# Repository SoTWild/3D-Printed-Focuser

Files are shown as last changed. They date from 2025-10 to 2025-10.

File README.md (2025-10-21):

# 3D打印颗粒对焦器

###### 【Designed By Dioxgen】

## 概述

这是一款基于 **SOLIDWORKS** 设计的 3D 打印**暗房颗粒对焦（放大）器**。

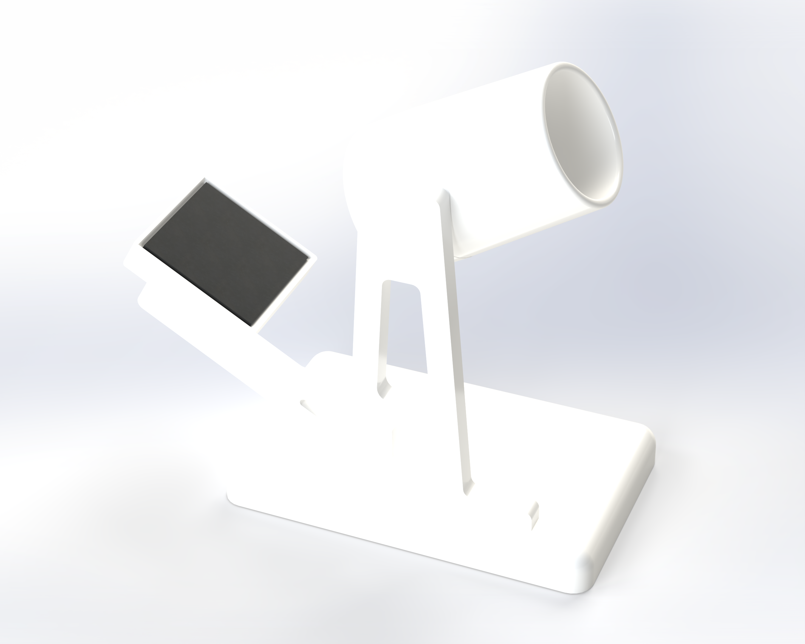
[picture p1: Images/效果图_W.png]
效果图_W


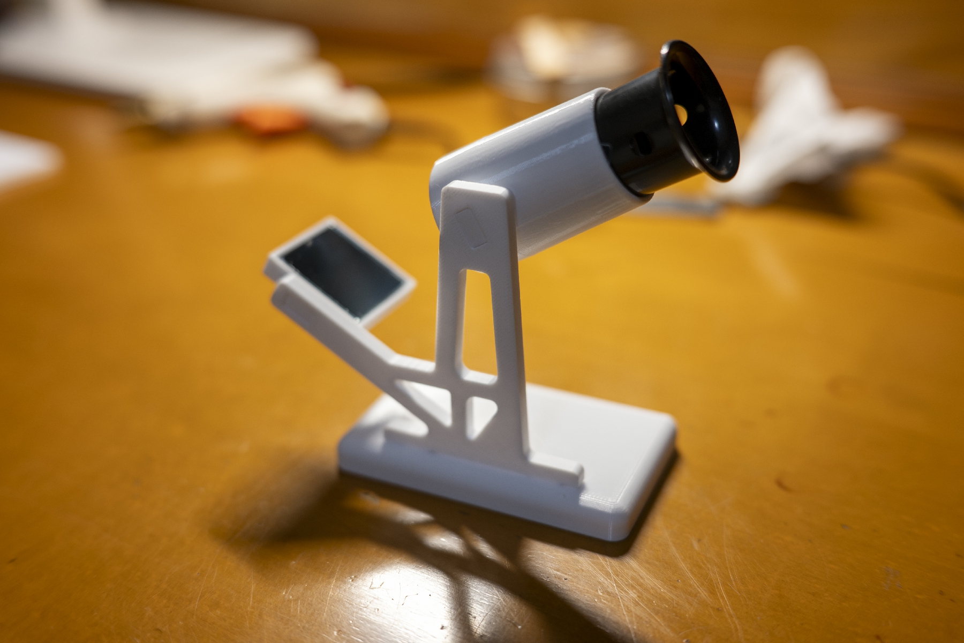
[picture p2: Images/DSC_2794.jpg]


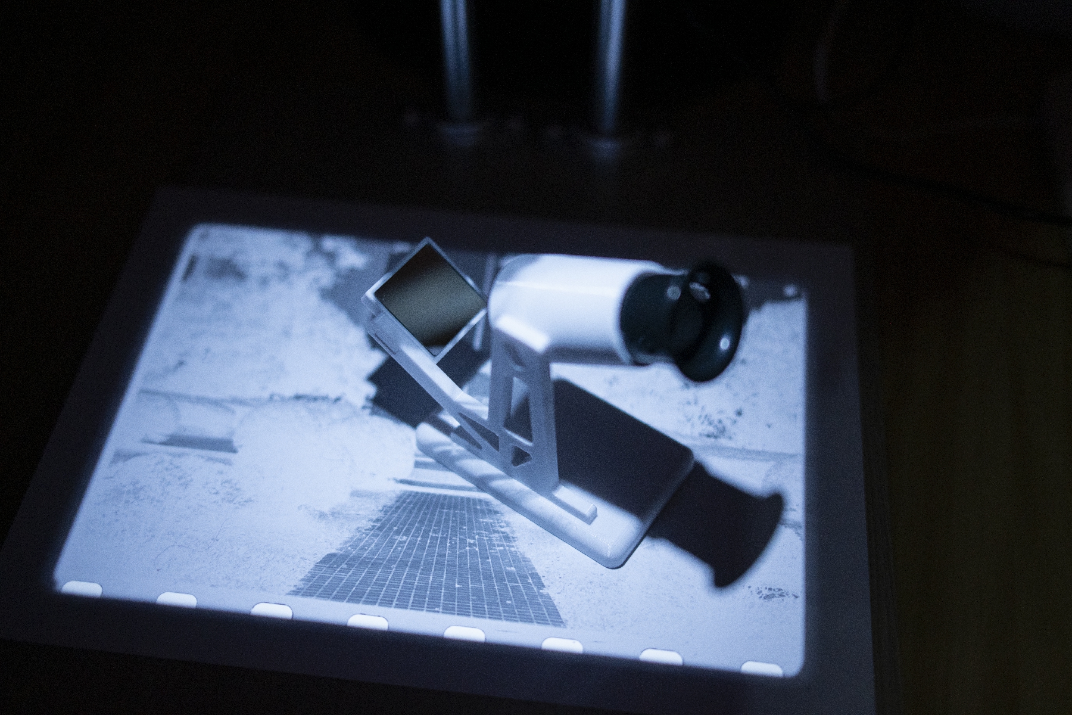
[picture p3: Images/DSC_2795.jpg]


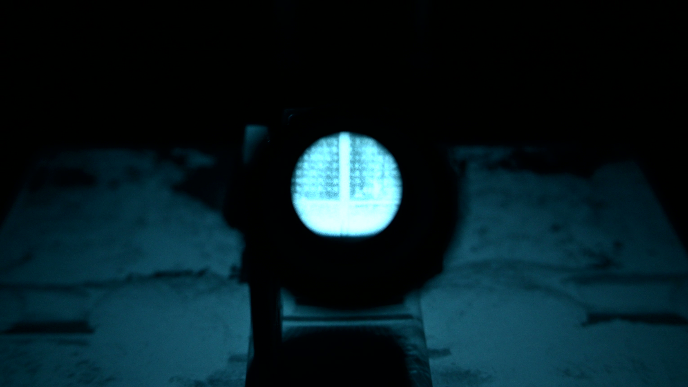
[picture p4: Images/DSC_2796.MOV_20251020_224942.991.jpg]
DSC_2796.MOV_20251020_224942.991


## 制作

### 准备：

#### 主体：

将 `STL` 文件夹中的 4 个组件全部 3D 打印。

以下是示例工艺：

> 黑色 PETG
>
> `15%` 填充

#### 目镜：

关键词：眼夹式目镜放大镜

规格：`5~10X` 放大

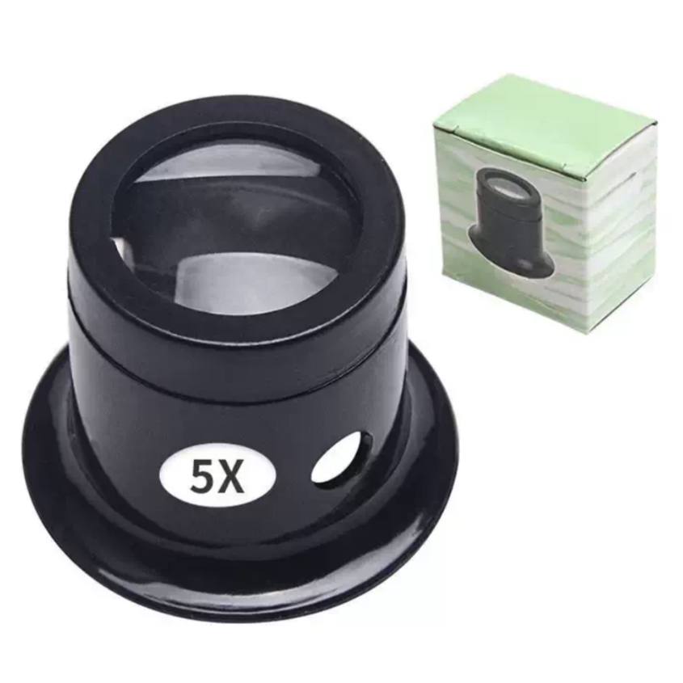
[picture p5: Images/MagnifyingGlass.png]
MagnifyingGlass


#### 镜片：

`3x3cm`，厚 `1mm` 平面镜。

#### 磨砂屏：

定制 `Φ=30mm`，厚 `2mm` 圆形亚克力**单面**磨砂片。

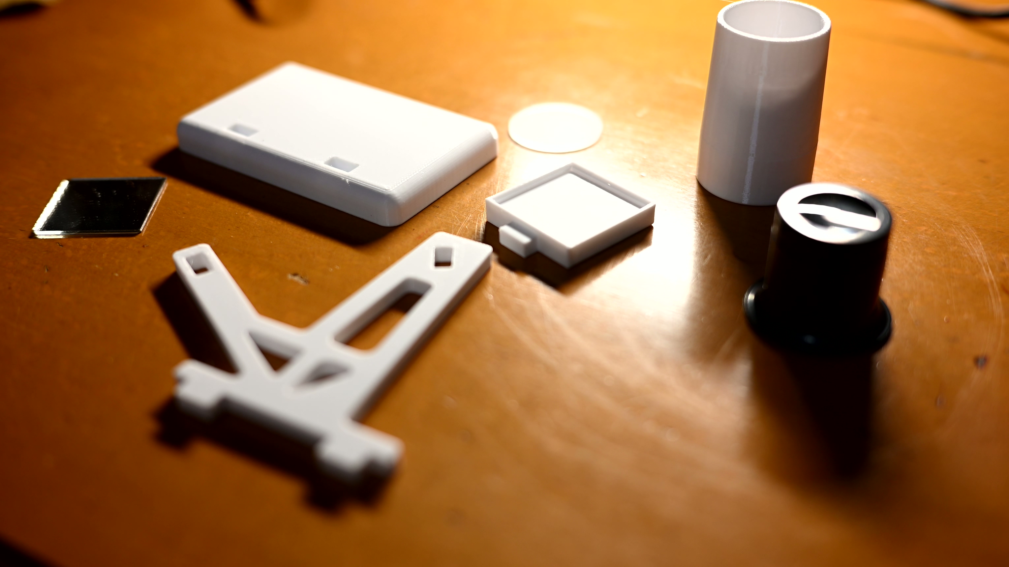
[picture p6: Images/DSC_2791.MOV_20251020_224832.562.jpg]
DSC_2791.MOV_20251020_224832.562


### 组装：

1）将 `磨砂屏` 通过少量胶水固定在 `目镜座` 较**大**开口的部位。

> 注：磨砂面朝**外**。

2）将 `目镜` 卡入、胶水固定至 `目镜座` 另一头。

3）将 `镜片` 通过少量胶水固定在 `镜片平台` 内。

4）将 `镜片平台` 和 `磨砂屏-目镜座` 嵌入 `支架` 中，随后，将这个装配体**嵌入** `底座`。

> 注：没有设置适当旷量，请稍作打磨后安装。

以上组装不计顺序。

### 原理：

利用**平面镜反射**原理，将放大镜头产生的实像反射至磨砂片处，同时保持总体光路**长度不变**。

> 这个例子中光路长度为 `49.01mm`。

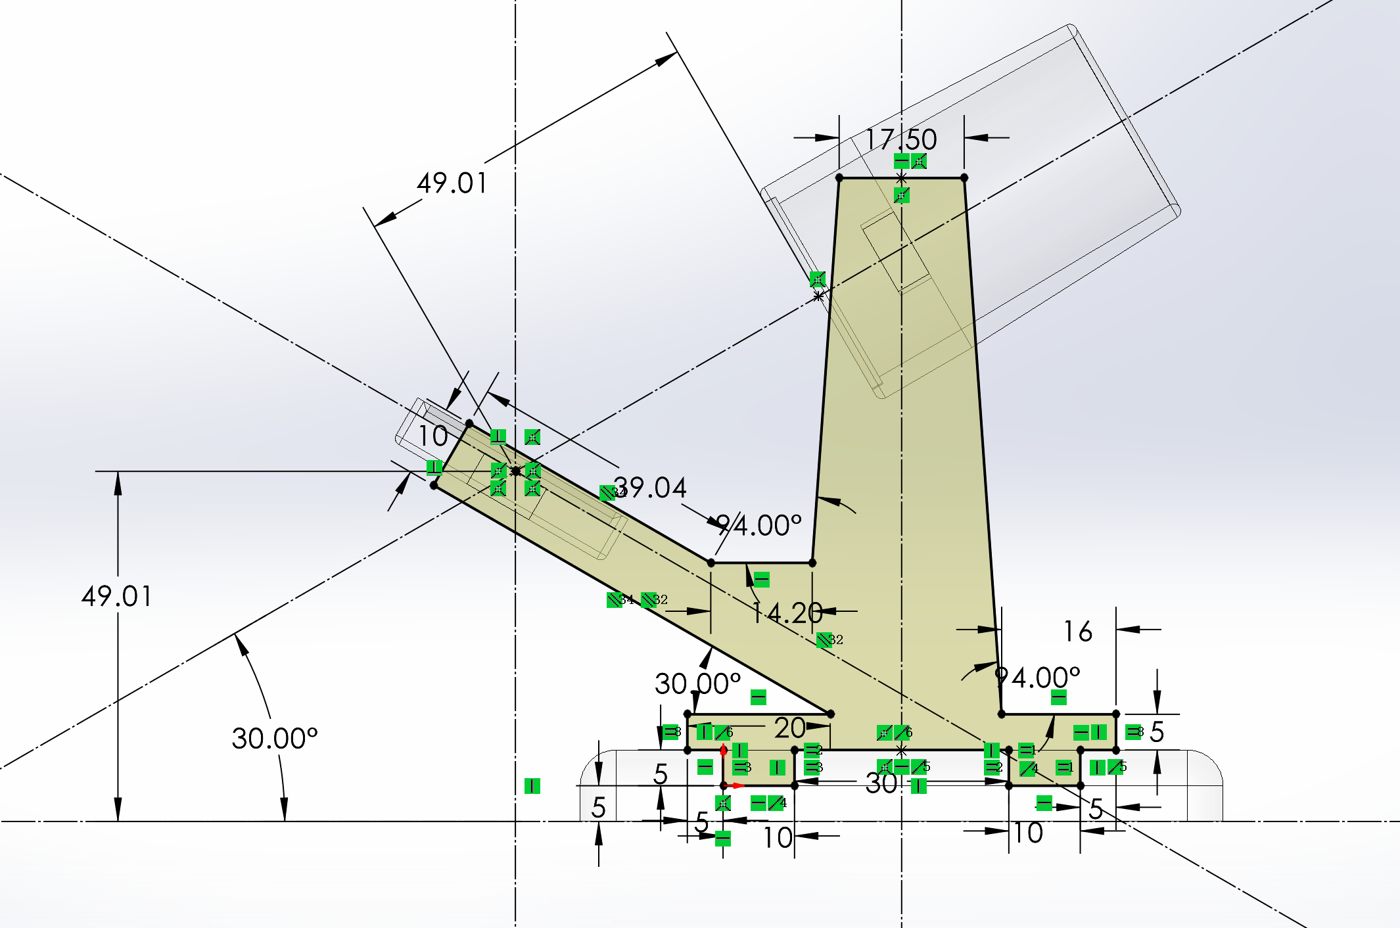
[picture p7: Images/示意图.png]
示意图


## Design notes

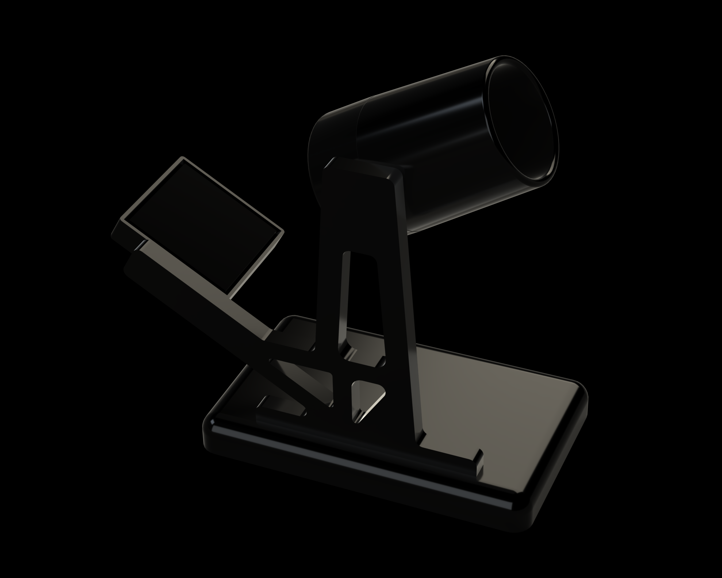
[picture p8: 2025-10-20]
Images/效果图_B.png

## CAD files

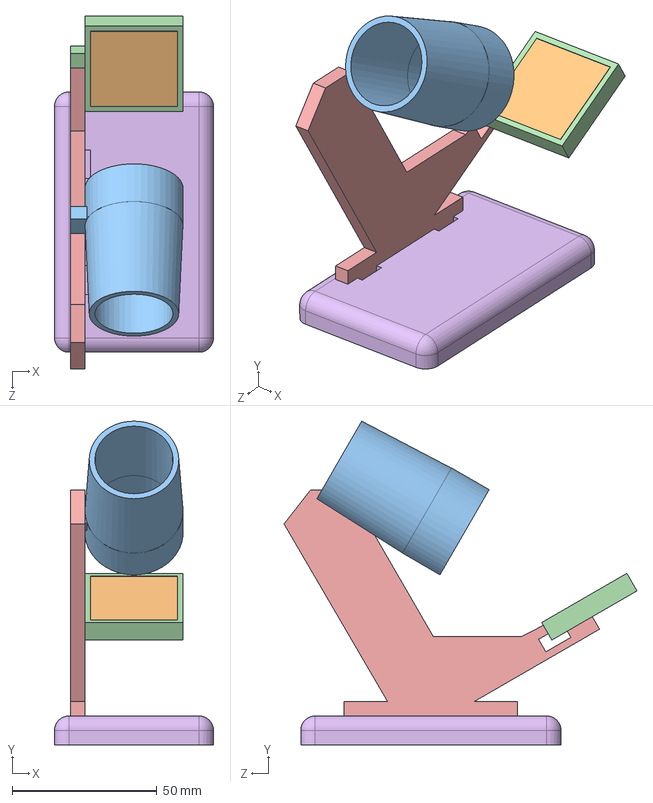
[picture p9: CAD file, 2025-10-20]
工程/颗粒对焦器_装配体.SLDASM
55.0 x 111.9 x 122.0 mm
底座
支架
镜片平台
磨砂屏-目镜座
镜面
单面磨砂片

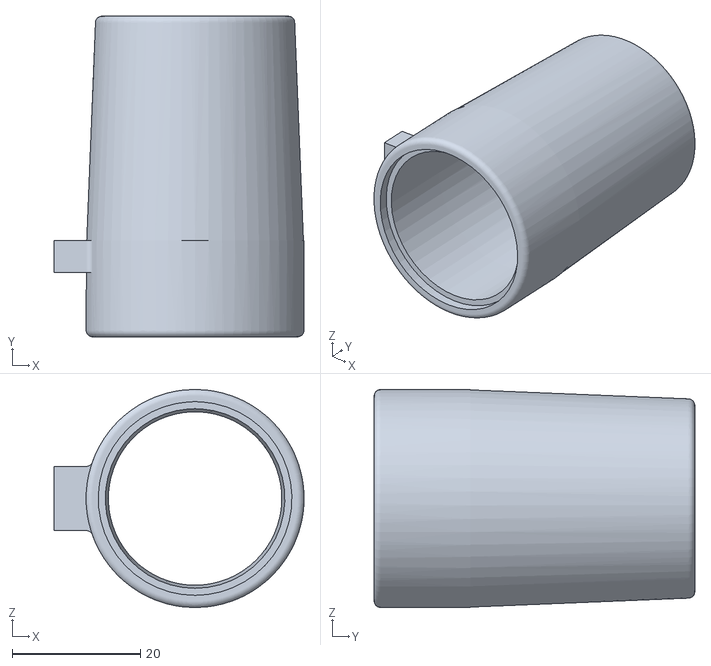
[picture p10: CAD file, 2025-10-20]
STL/磨砂屏-目镜座.STL
39.0 x 50.0 x 34.0

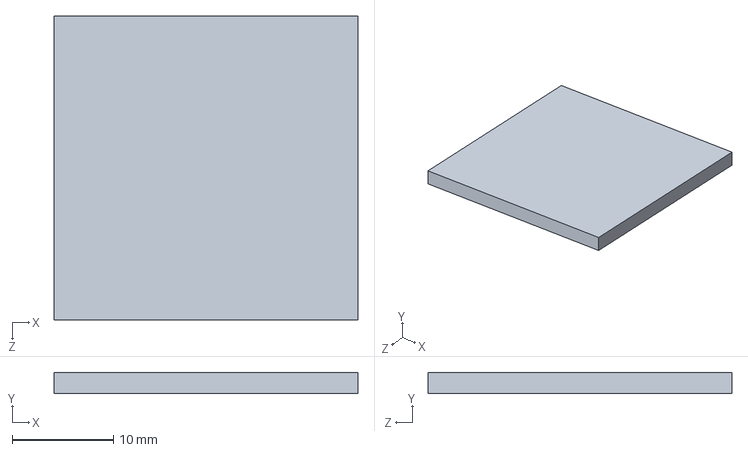
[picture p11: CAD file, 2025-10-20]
工程/镜面.SLDPRT
30.0 x 2.08 x 30.0 mm

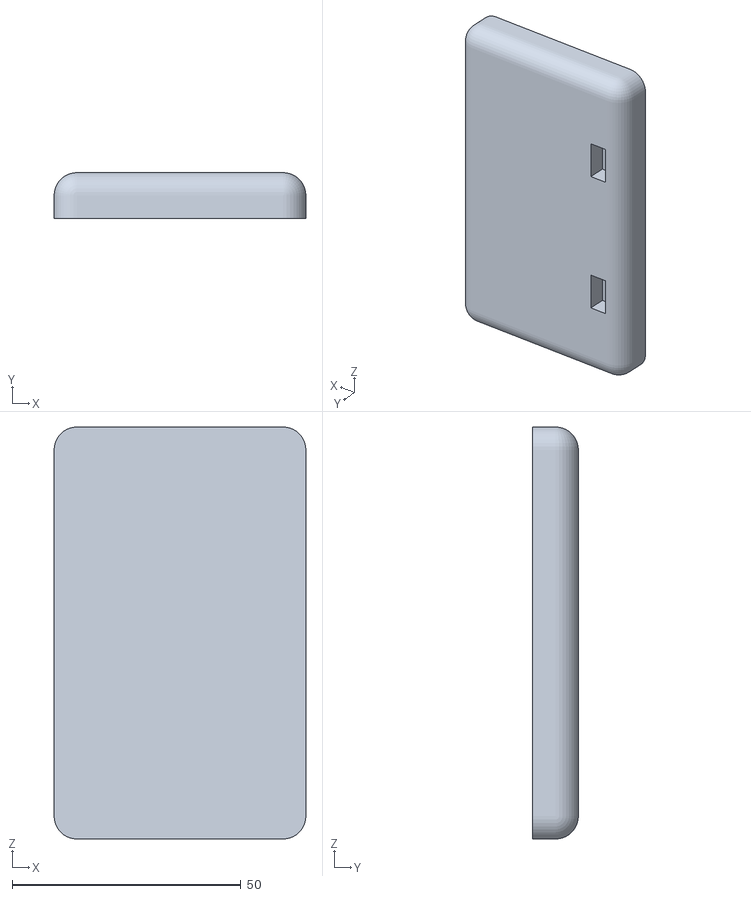
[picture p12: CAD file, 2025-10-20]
STL/底座.STL
55.0 x 10.0 x 90.0

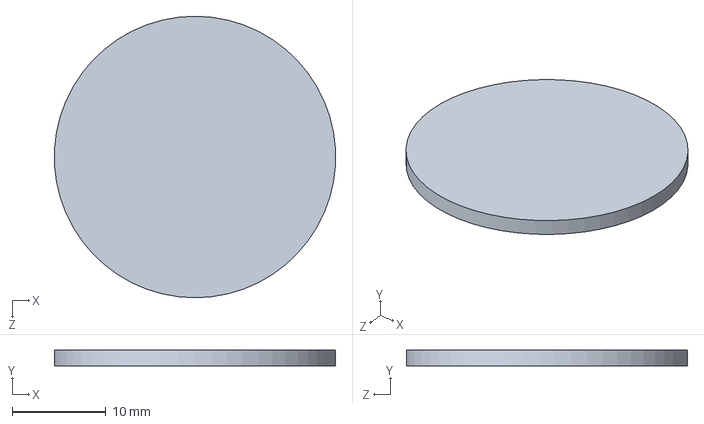
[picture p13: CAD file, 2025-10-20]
工程/单面磨砂片.SLDPRT
29.9 x 1.70 x 30.0 mm

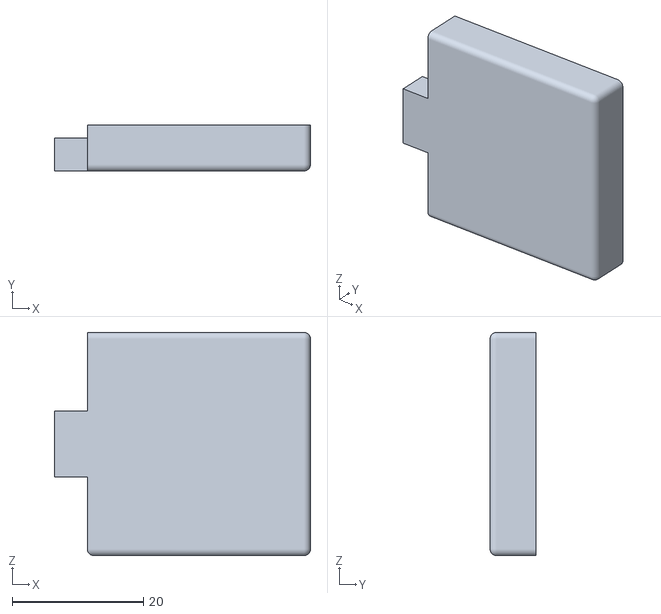
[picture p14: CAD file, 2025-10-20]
STL/镜片平台.STL
39.0 x 7.00 x 34.0

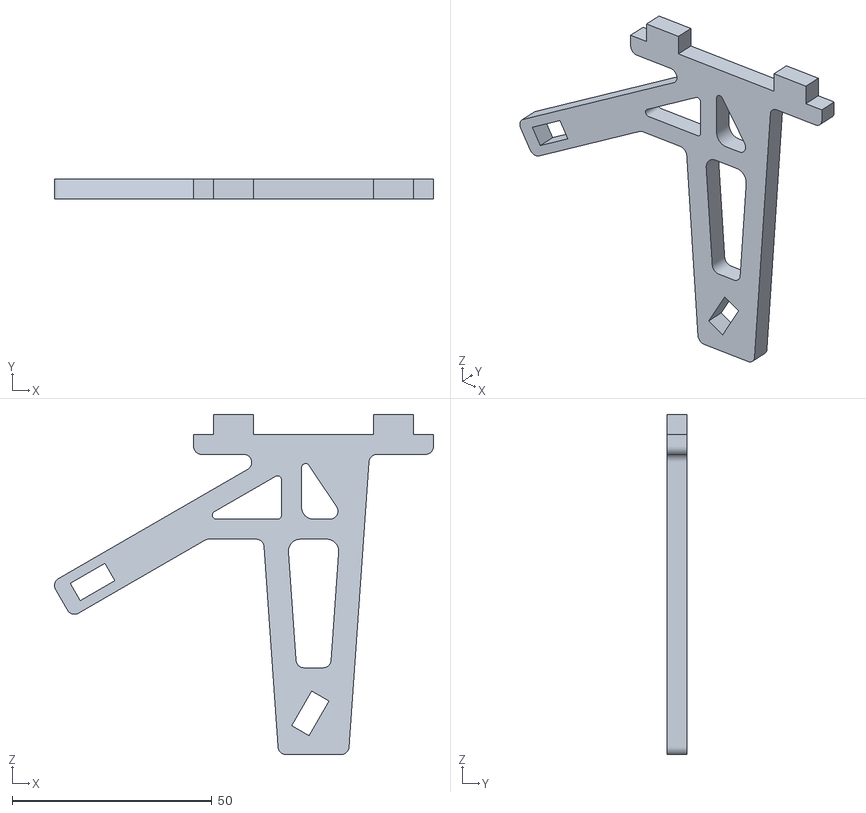
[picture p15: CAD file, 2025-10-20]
STL/支架.STL
94.8 x 5.00 x 85.1

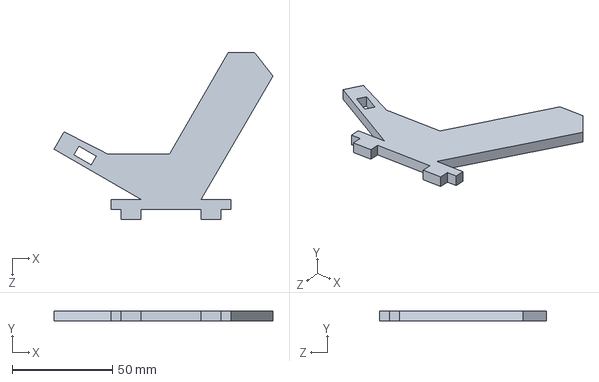
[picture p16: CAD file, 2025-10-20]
工程/支架.SLDPRT
109.1 x 5.00 x 83.1 mm

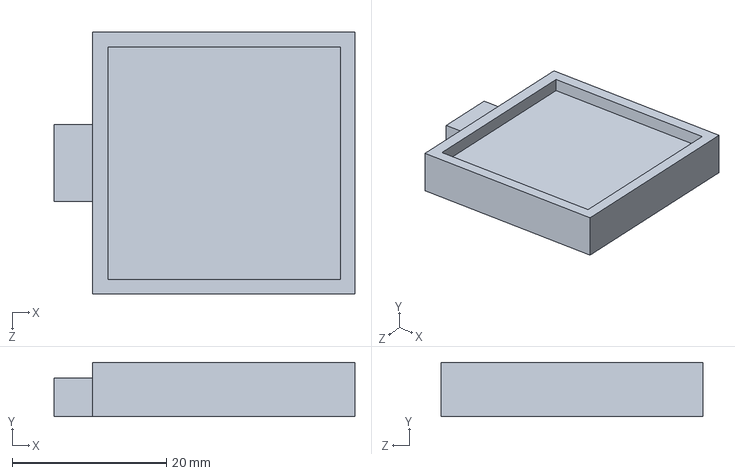
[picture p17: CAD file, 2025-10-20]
工程/镜片平台.SLDPRT
39.0 x 7.00 x 34.0 mm

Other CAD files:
工程/磨砂屏-目镜座.SLDPRT
工程/底座.SLDPRT

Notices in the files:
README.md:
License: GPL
